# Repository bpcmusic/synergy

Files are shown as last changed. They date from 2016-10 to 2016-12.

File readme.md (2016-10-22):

#bpcmusic's dk synergy corner

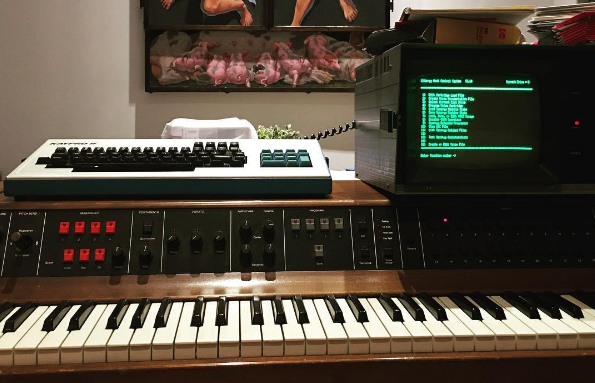
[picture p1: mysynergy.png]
My Synergy


I'm creating this archive as a place to document my attempts to restore a DK Synergy II+ (#1398) that was purchased in the fall of 2016 as a part of my #midlifesynthcrisis or #midilifecrisis. :) I'll also be sharing a lot of photos on [my personal Instagram](http://instagram.com/bpcmusic).

Along the way, I'll store the relevant things that I learn here. While I am relatively handy with electronics, this is the first vintage synth project that I've undertaken. 

##My Journey

* [Taking the Synergy Apart](teardown.md)
* [Replacing the Aging Capacitors](capacitors.md)
* Installing Headers for Board Connections
* [Restoring the Wood Case](case.md)
* [Replacing the Power Supply and Noisy Fan](powersupply.md)
* [Fixing Sticky Buttons](stickybuttons.md)
* [Connecting to the Kaypro II](kaypro.md)
* Replacing the Kaypro II Disk Drive with a Floppy Emulator
* [Building a Cartridge PCB and 3D Printed Shell](cartridge.md)
* [Keyboard Refurbishment](keyboard.md)

##Handy Resources

* [Synergy Resource Page](http://users.ece.gatech.edu/lanterma/synergy/)
* [Facebook Synergy Group](https://www.facebook.com/groups/synergysynth/)
* [Yahoo Synergy Group](https://groups.yahoo.com/neo/groups/synergy-synth/info)
* [Vintage Synth](http://www.vintagesynth.com/misc/synergy.php)
* [Old Crow's Vintage Synth Tips](http://www.oldcrows.net/~oldcrow/synth/tips.txt)
* [HxC Floppy Emulator](http://hxc2001.free.fr/floppy_drive_emulator/)
* [Syntaur Synergy Parts](https://syntaur.com/synergy.html)

##Synergy Videos

* Rex Coggins has compiled a YouTube playlist that covers a whole bunch of Synergy-related videos up on YouTube; check it out at [https://www.youtube.com/playlist?list=PLffUjChiMD5i-BCu7Go9ABLnsAaPviy90](https://www.youtube.com/playlist?list=PLffUjChiMD5i-BCu7Go9ABLnsAaPviy90) 

##Nice Helpful Folks

* Major thanks to **Brian McLaren** (made a few of those YouTube videos up there). He has gone above and beyond with me helping get the instrument 100% with my software, EPROMs and general usage questions.
* Thanks to **Rex Coggins** for his advice and recommendations.
* Thanks to **Alexander Guelfenberg** at [Virtual Music](http://virtual-music.at/webseiten_e/zubehoer/dk.htm) - insanely nice and helpful in my trek to refurbish the Synergy.

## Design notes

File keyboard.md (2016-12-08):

[< BACK](readme.md)

#Keyboard Refurbishment

This section covers my refurbishment of the DK Synergy Keyboard. You will find details on removing the keys, cleaning/whitening, 3D printing actuator replacements, replacing the rubber bushings, and reinstalling the keys.

##On the Universal Keyboard Upgrade

There is a "universal keyboard upgrade" that you can find on the [Virtual Music site](http://virtual-music.at/webseiten_e/zubehoer/dk.htm). I reached out to Alexander Guelfenberg at Virtual Music about getting his upgrade and found it wasn't offered for the Synergy anymore. Here is what he shared with me:

	All items were fitting when I had my personal Synergy. And I saw that all PPG parts worked for that. 
	But then a client told me that his knobs are quite different so they did not fit.

I should point out that he is an insanely nice person and has been extremely helpful with my Synergy work.

##Removing Keys

Removing the keys from the Pratt-Read assembly is pretty straightforward. Screws in my Synergy Keyboard were easily managed using a 5/32" socket wrench. This was a little hard to find at my local Home Depot, it literally was the smallest socket that they had (and there was only one of them in stock).

I went ahead and labeled all of my keys with blue tape up on the metal bit. They are labeled themselves as to which location they fit, but in order to avoid having keys placed in different octaves than their original source, I took the OCD way out. I figured if the wear and yellowing was uneven across the keyboard, making sure that they keys were put back in their original octave would keep things looking as uniform as possible. Thus, I haven't documented the factory labeling scheme for the keys.

What I did learn quickly is that all white keys need to be removed from around any of the black keys for disassembly and the reverse for reassembly. Due to this (and due to the fact that my cleaning procedures are different for white vs. black keys), I removed all of the white keys first and then followed it up with the black keys.

My steps for removal of the keys:

1. Remove the screw at the fulcrum point (middle of the metal key bar).
2. Remove the metal side spring by gently lifting it off of the plastic actuator and releasing it to the side of the key.
3. Lift the key up by the back and, when released, slide the key forward. (The little metal spring that inserts into the back of the actuator will simply pop out.)
4. Carefully remove the rear screw that holds the actuator in place.
5. Slide the back dingus off of the actuator. Sorry - I don't know what else to call it. It is the plastic bit that sticks up and has a few holes on it. It connects to the actuator using a rubbery ring.

That's it.

    Note: I wasn't able to figure out how to separate the white plastic key from the metal bar safely. 
    I decided to leave it on and be very careful during the cleaning.

##Cleaning the Keys

I followed a procedure that I found here:

http://www.retrofixes.com/2013/10/how-to-clean-whiten-yellowed-plastics.html

*It is highly recommended to use eye protection and operate in a well-ventilated area.*

####White Keys

Check out the difference before and after cleaning:

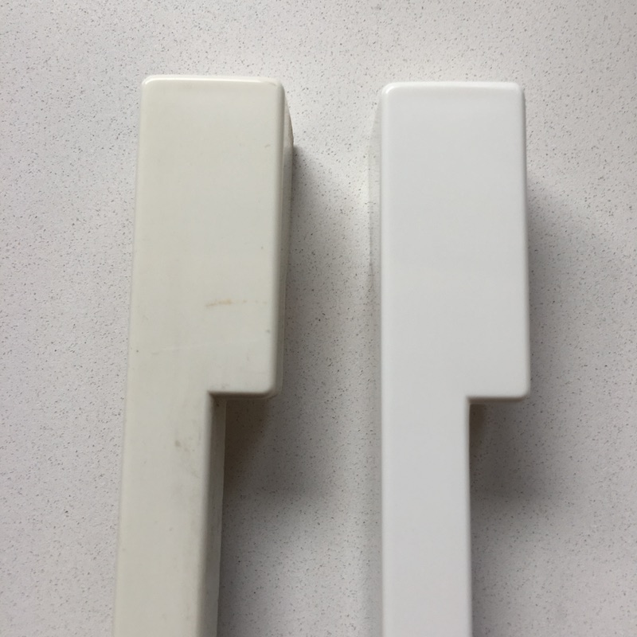
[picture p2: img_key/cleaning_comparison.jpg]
Old vs New


Left group hasn't been done; right group has:

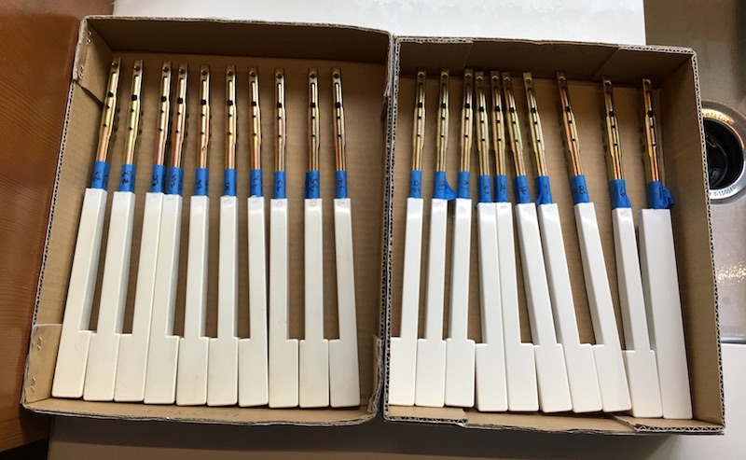
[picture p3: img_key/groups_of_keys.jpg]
Ready vs Done


**The Procedure:**

1. Wash the oil and filth off of the keys using an OxiClean + Water solution and a toothbrush. (Due to the fact that I could not remove the metal bits from the keys, I did not go through a soaking process.)
2. Liberally apply a hydrogen peroxide 12% solution (the Clairol Hair Color product below) to the plastic part of the key - careful to keep it off of the metal.
3. Place the keys under a strong UV light for 3-4 hours.
4. Immediately remove the keys, clean them with water, reapply the peroxide solution, and return them to the "UV bath" for another 3-4 hours.
5. Remove the keys, clean them with water and dry them.

Depending on the desired whiteness, I imagine that several more trips to the UV bath could be done. I elected to be conservative with my whiteness levels.

My homemade UV tank:

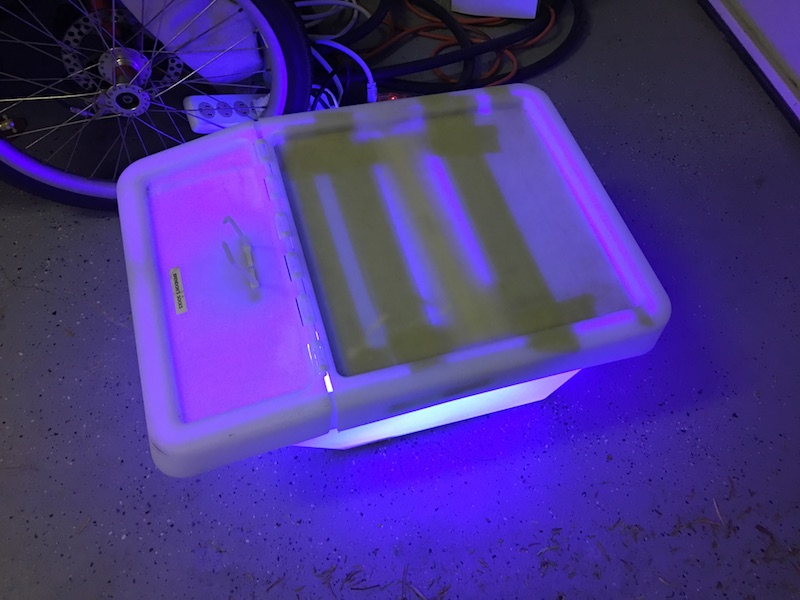
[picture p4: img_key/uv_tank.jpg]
UV Tank


I used two UV lamps I found on Amazon (and liberal amounts of duct tape):

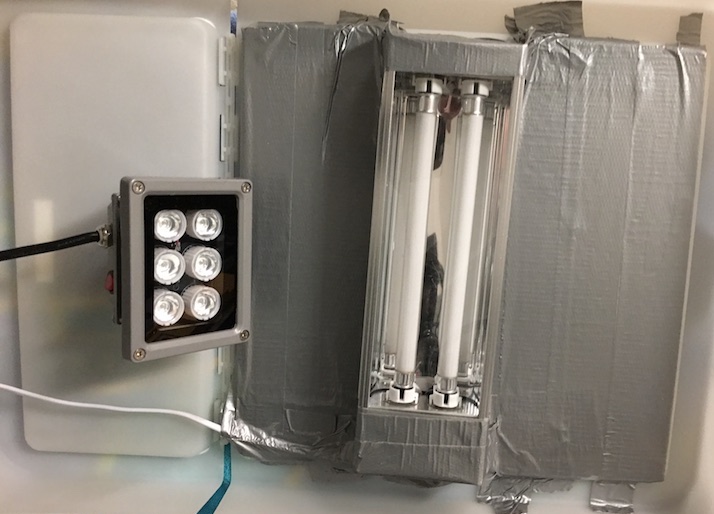
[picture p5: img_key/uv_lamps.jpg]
UV Lamps


    IMPORTANT: At no point do you want the peroxide to dry as it can scar the plastic surface of the keys. 
    Set an alarm or other timer. These things are irreplaceable as far as I can tell.

####Black Keys

I simply washed the keys using the OxiClean + Water Solution using a toothbrush. They cleaned up nicely.

##Key Actuators

I first cleaned the actuators with rubbing alcohol wipes as they were covered in a sticky substance. Yuk.

I found ten plastic actuators in my Synergy that were cracked or cracking. All of the damage was found at the joint where the screw enters the body of the actuator. The sticky substance was an aid in this as it helped find the cracked actuators by making the cracks stand out.

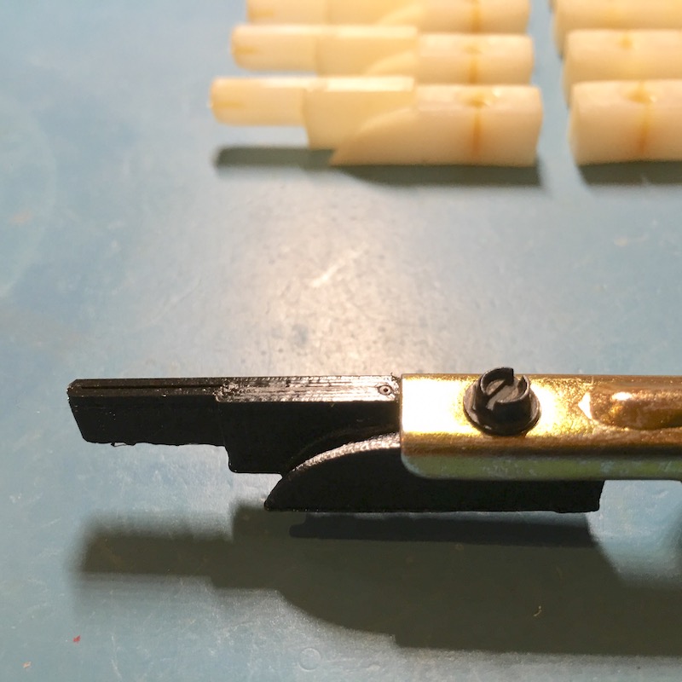
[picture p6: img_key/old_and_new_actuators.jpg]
New and Old Actuators


To solve this, I modeled and 3D printed replacements for the failing parts. I tried printing in both PLA and ABS and found that ABS was far superior in producing a part that worked mechanically. The PLA would start sticking after only a few keypresses; I have yet to replicate that behavior with the ABS printed parts. There are more abrasion-resistant 3D filaments - I have yet to test any of them.

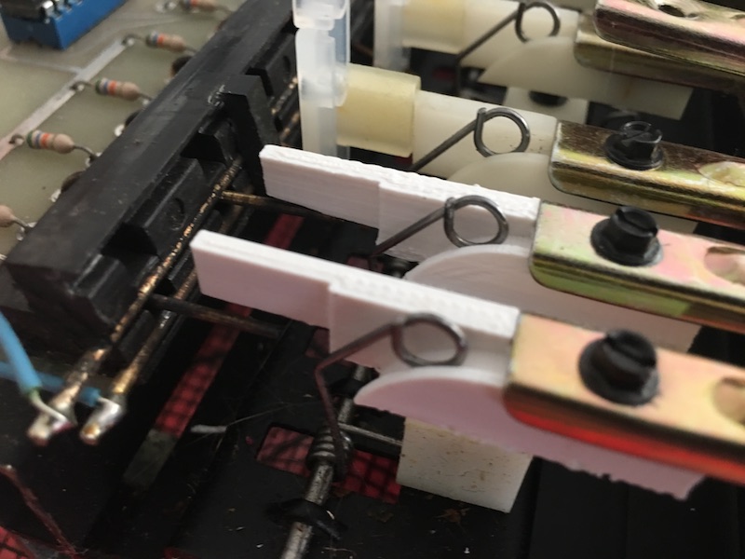
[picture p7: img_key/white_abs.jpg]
White ABS Actuators


Here are the files for the replacement actuator:

* [Download the OpenSCAD Model](actuator/actuator.scad)
* [Download the STL Part File](actuator/actuator.stl)

These files are released under the [cc-by-sa-3](https://creativecommons.org/licenses/by-sa/3.0/us/) license. Hopefully you find it helpful!

##Rubber Bushings

If you need new Rubber Key Bushings for the Pratt-Read keyboard assembly, Syntaur has them.

[Syntaur Link for Pratt-Read Rubber Bushings](http://syntaur.com/Items/4169.html)

The Synergy has 74 keys and, thus, needs 74 bushings for a total replacement. At the time of this writing, they were $0.70 USD per bushing.

I grabbed a full set. After inspecting my bushings, I realized that they were still doing pretty well. Rather than throwing them away, I went ahead and conditioned them with Armor All Original Protectant and reinstalled them. I'll keep the new ones for a rainy day.

*Using Armor All is the recommended treatment that I found for the rubber bits in the Keyboard.*

##Reassembly

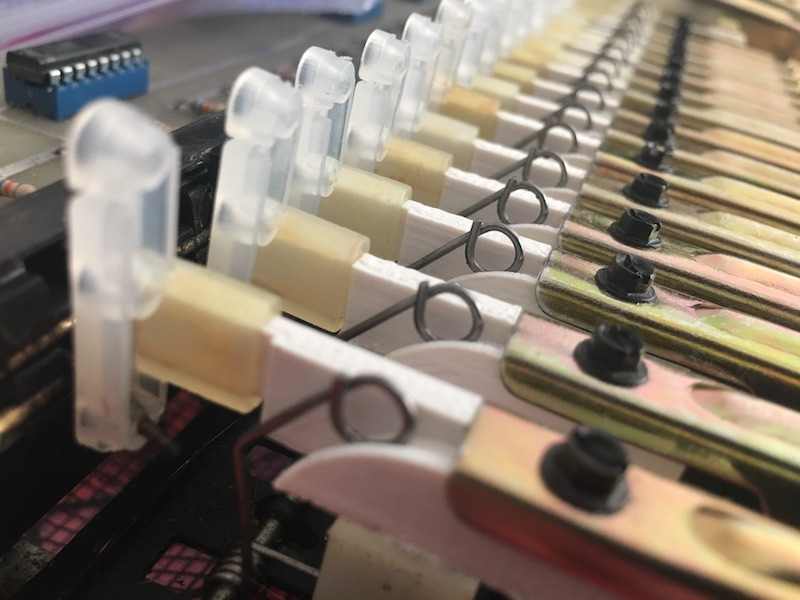
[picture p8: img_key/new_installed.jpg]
White ABS Actuators during Reassembly


Reassembly is simply the reverse of the removal process. Remember, do the BLACK KEYS first to make it easy on yourself.

1. Attach the actuator back to the far end of the metal key body. Careful not to over-tighten the screw.
2. Attach the dingus to the end of the actuator. I recommend treating the rubbery ring with a coating of Armor All prior to reattachment.
3. Slide the plastic end of the key under the lip at the front of the assembly.
4. Press the key down onto the white plastic fulcrum; you might need to make sure that the part that it attaches to is properly centered for easy reattachment.
5. Using some sort of clever implement (I used a pair of SMD tweezers), pull the metal spring up and back over the curved area of the actuator.
6. Reattach the screw at the fulcrum point. Again, careful not to over-tighten it.
7. Carefully manipulate the spring at the far end of the key back into the appropriate hole in the dingus. I was able to pull the spring back in a bit from the other side of the black metal bar so as to realign it with the hole.

##Products Used

* [OxiClean at Amazon](https://www.amazon.com/gp/product/B005GI8UOO/ref=oh_aui_search_detailpage?ie=UTF8&psc=1)
* [Clairol Professional Soy4plex Pure White Creme Hair Color Developer at Amazon](https://www.amazon.com/gp/product/B00A5ET16A/ref=oh_aui_search_detailpage?ie=UTF8&psc=1)
* General Cheap Toothbrushes (drugstore brand); I used a motorized one in addition to a few plain ones for extra fun.
* [6-LED UV Lamp for Curing LOCA UV GLUE - 110V at Amazon](https://www.amazon.com/gp/product/B0178KPN4W/ref=oh_aui_search_detailpage?ie=UTF8&psc=1)
* [HQMaster 110V 48W Curing UV Light Ultraviolet Lamp to Bake Loca Glue for Refurbish LCD no Handle at Amazon
](https://www.amazon.com/gp/product/B012ZNLZY4/ref=oh_aui_search_detailpage?ie=UTF8&psc=1)
* [Armor All 10228 Original Protectant at Amazon](https://www.amazon.com/Armor-All-10228-Original-Protectant/dp/B0007898UI)

##Research

I found these videos for Pratt-Read Keyboards - though the assemblies do not match the Synergy.

* [ARP Pro Pratt-Read Keyboard Restoration](https://www.youtube.com/watch?v=5iJtaW3bvK4)
* [Pratt-Read Key Removal on OB-Xa](https://www.youtube.com/watch?v=DmSz_JY4zZU)
* [Pratt-Read Keyboard Restoration Video](https://www.youtube.com/watch?v=VvMh64XNhEw)

##License for Original Materials

The original materials made available on this page are licensed under the [cc-by-sa-3](https://creativecommons.org/licenses/by-sa/3.0/us/) license.

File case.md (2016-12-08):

[< BACK](readme.md)

# Restoring the Wood Case

##Context and a Plan

So - my Synergy is currently a medium-brown wood. It has some damage, but isn't horrible. Basic scratches and light gouges around the body. Only one place on the primary face where a little of the surface is chipped off. Each of the four corners of the base is crushed in a bit.

My Synergy

My analysis is that this is what an upright piano looks like after a few moves in a family with toddlers. Rather than try to fix it myself, I'm looking for a piano refinisher in the LA area to fix it as I have no experience restoring wood with this type of damage.  I figure they would be the best with this kind of problem - especially since the body of the Synergy is like a big piece of wood furniture (like a piano).

Here is what it looked like when I purchased it:

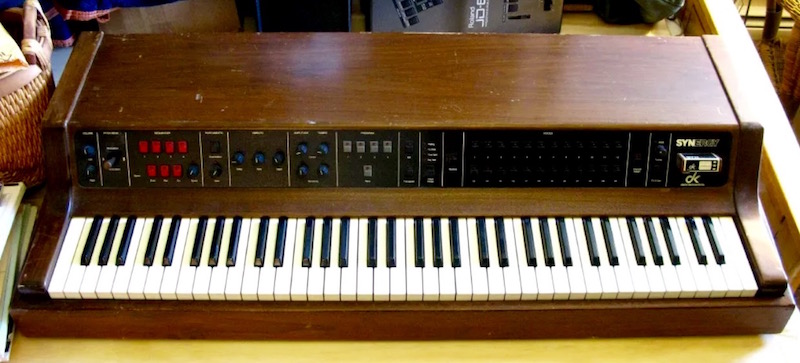
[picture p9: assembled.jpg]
Assembled


Note the damage to the corners of the base (all four are similar):

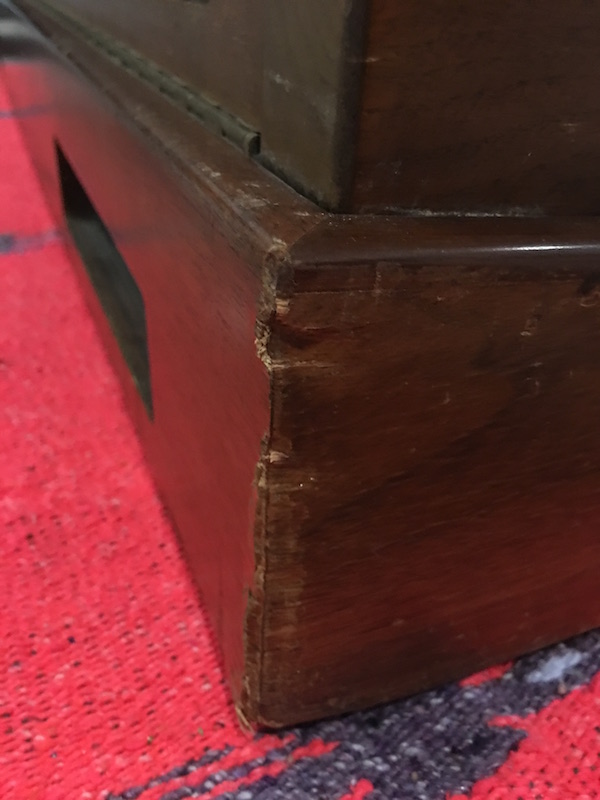
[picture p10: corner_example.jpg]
Corners


The fact that I've decided to bring in a professional refinisher opens up the question as to whether I'm going to keep the brown wood or do something else.

*Calm down, I'm not doing the Murf and the Magic Tones pink fur treatment. Though - you have to admit it would be awesome. :)*

I'm actually considering refinishing it in a black lacquer piano finish. Something like this:

Piano Black Synergy

Crossed with this:

LaCie Drive in Piano Finish

Should look beautiful. Couple of points:

* The ends of my brown Synergy are shaped a little differently and I'm not planning to change that. 
* The black Synergy keyboards that I've seen have a tolex-wrapped base. As I don't plan to travel with the instrument, if I piano-black the thing, I'll probably just do the whole body.

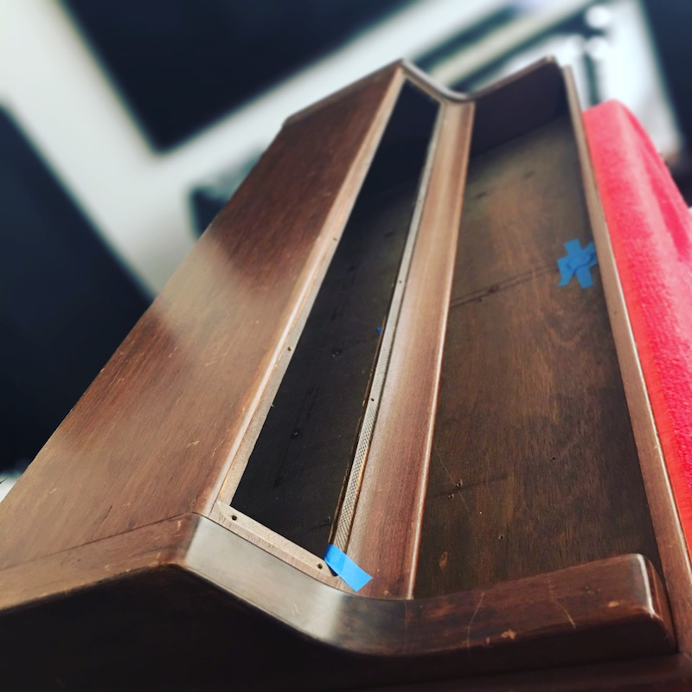
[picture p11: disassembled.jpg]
Disassembled


##Results

It turned out amazingly well. Total for the case refurbishment (repair and refinishing) was around $1300 in LA. Considering how banged up it was, they did a wonderful job.

Check out some early pictures:

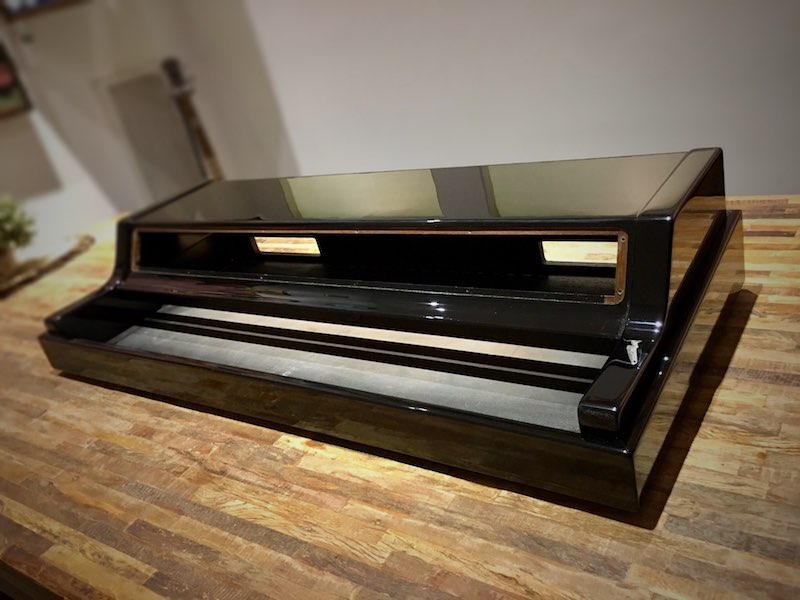
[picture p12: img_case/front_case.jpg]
Front Case


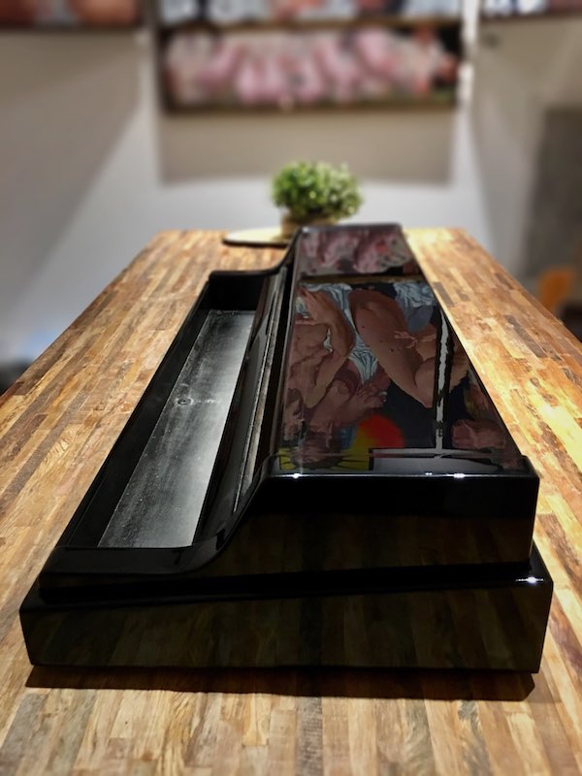
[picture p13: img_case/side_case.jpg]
Side Case


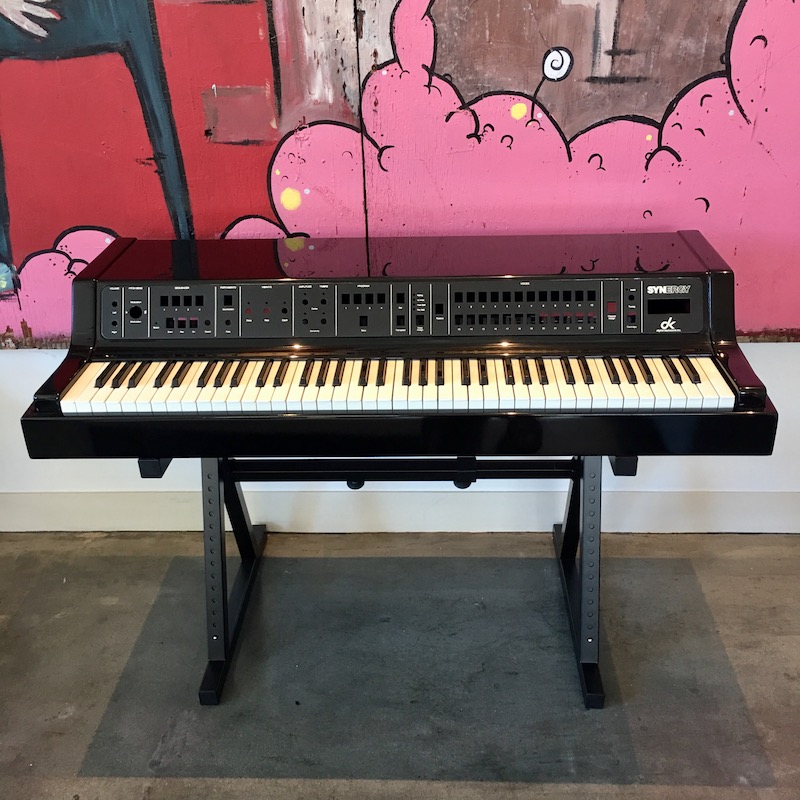
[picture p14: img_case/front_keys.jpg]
Front Keys


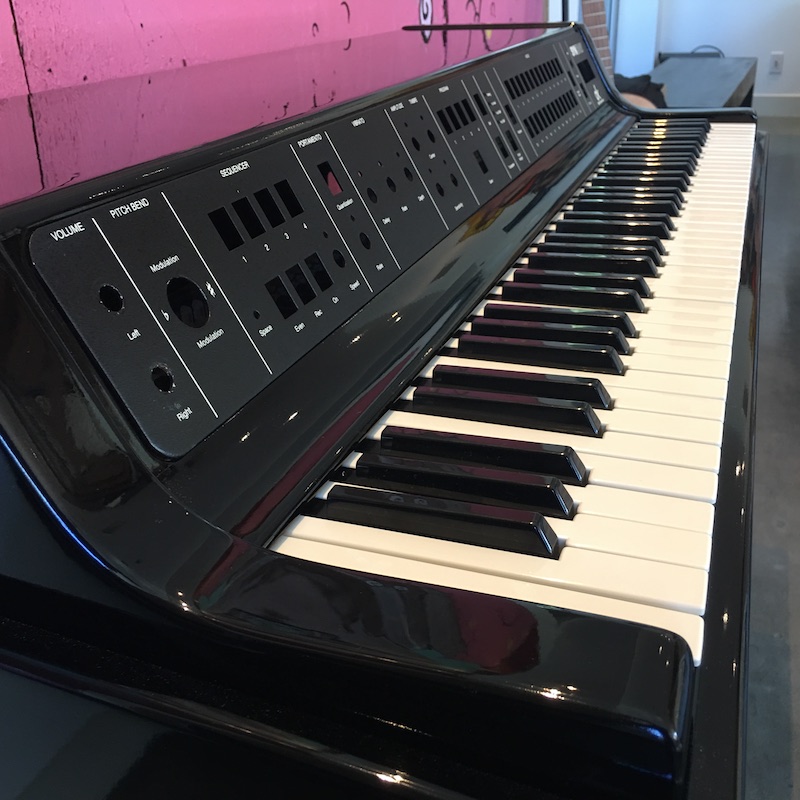
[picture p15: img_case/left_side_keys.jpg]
Left Side Keys


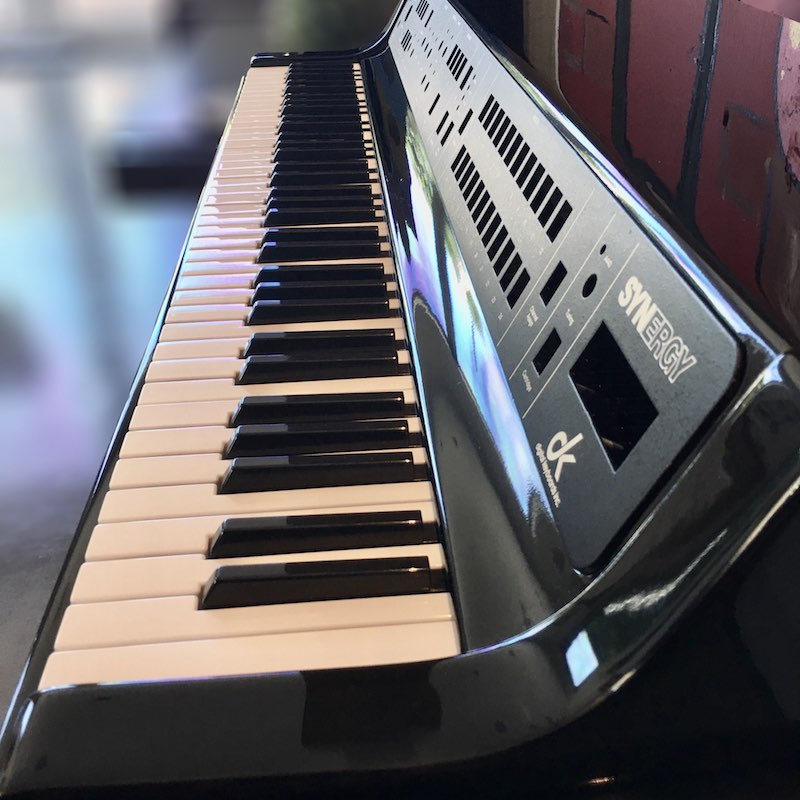
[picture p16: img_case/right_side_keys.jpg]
Right Side Keys


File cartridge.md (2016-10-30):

[< BACK](readme.md)

#Synergy Cartridge

I have a complete set of all of the EPROMs for the Synergy - including all of the cartridges. I'd like to fit these into actual cartridges to have along side my Synergy (as opposed to using some sort of socket adapter or a multi-cartridge device). 

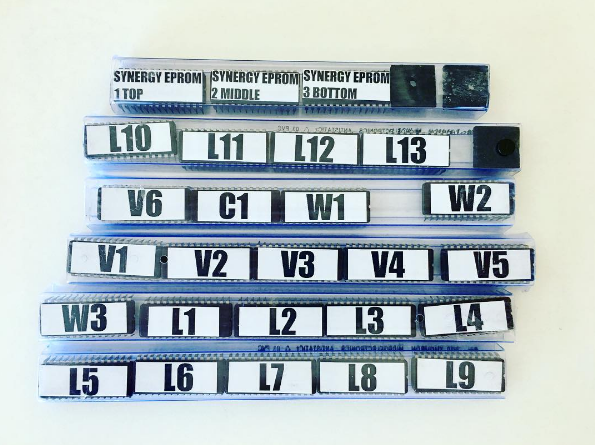
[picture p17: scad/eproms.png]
EPROMs


*I know what you are thinking. Yes, these are also available using SYNHCS on the Kaypro II (they are all archived on the collection of voice disks that I have), but I wanted to have a full set of cartridges to go with it so I don't have to always boot up the Kaypro II.*

According to Dan Wilson of Hideaway Studio, the Synergy uses cartridge bodies and PCBs that are compatible with the vintage Atari 400 computer game console. In my cursory research, this seems to be the case.  If I had just a few cartridges to do I could eBay a handful of cartridges, mod the PCB and be off to the races.

As I have 23 cartridges to make (and enjoy a good challenge), I decided to 3D print my own custom case (based off a vintage Synergy voice cartridge) and replicate the PCB in Eagle.

##MY PLAN:

* Design a new Cartridge Body in OpenSCAD [*DONE*]
* 3D Print 23 Cases [*In-Process*]
* Replicate the PCB in Eagle [*DONE*]
* Do a Test Run of the PCB at OSH Park [*In-Process*]
* Assemble, Test and Tweak the PCB
* Find and Affordable PCB Manufacturer that can Gold Plate the Edges
* Get >23 PCBs Made with Gold Plated Edges
* Assemble All Carts

##3D PRINTED CARTRIDGE BODY

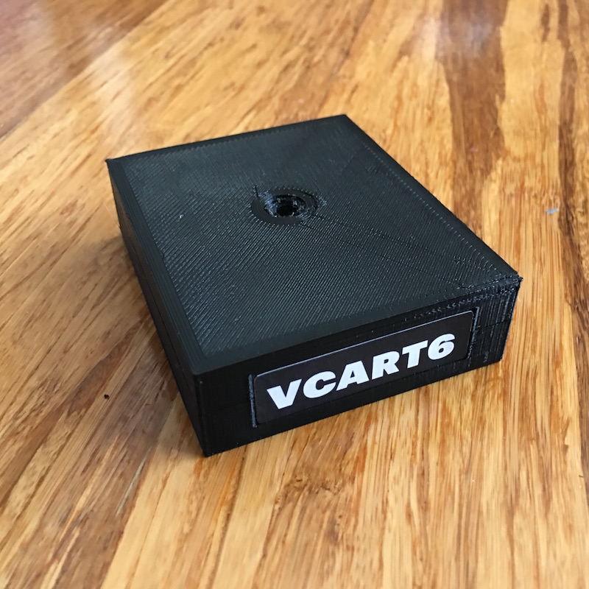
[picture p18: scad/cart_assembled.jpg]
Assembled Cartridge with Label


The cart body is in two parts - the top and the bottom. While it is close to the original, I've made some modifications to better support 3D printing. Primarily, there are now 5 little plastic studs in the four corners and top center to make the body way more rigid (the original only had one in the top center location). I also changed the label system to use a single 0.5" x 1.75" mailing label on the top end (as opposed to the wraparound label.

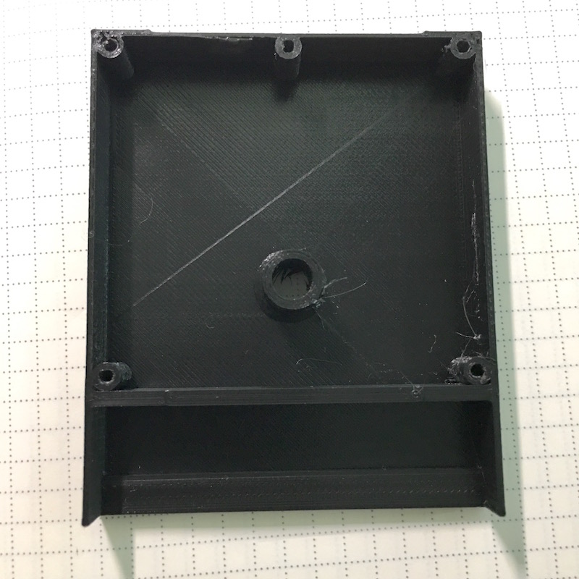
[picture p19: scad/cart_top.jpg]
Top

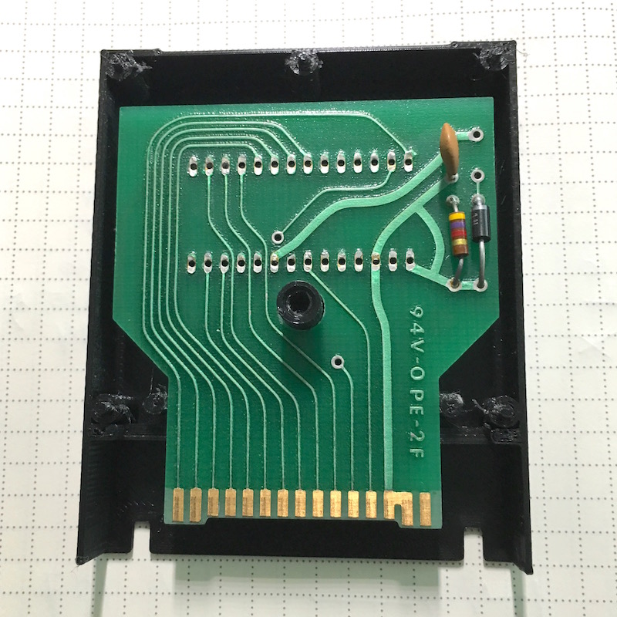
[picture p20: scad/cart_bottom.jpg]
Bottom


You are welcome to grab the STL and/or OpenSCAD files to play around with it (covered under the cc-by-sa-3 license; see the bottom of this page). I've been printing on my NewMatter Mod-T with PLA. If you are using a different printer, the tolerances may be different. Let me know if you have any issues.

* [Top STL File](scad/synergycart-top.stl)
* [Bottom STL File](scad/synergycart-bottom.stl)
* [OpenSCAD File](scad/synergycart.scad)

The cartridge is designed to support a standard 0.5" x 1.75" mailing label on the end; I ordered this product from Amazon to laser print my labels:

[Avery Easy Peel Return Address Labels for Laser Printers, 0.5 x 1.75 Inches, White, Pack of 2000 (5267)](https://www.amazon.com/gp/product/B00004Z5QP)

You will also need a 1/2 inch #6 wood screw (0.138" major thread diameter and .279" head diameter) with a crown top for each cartridge.

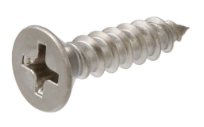
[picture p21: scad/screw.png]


##CARTRIDGE PCB

As opposed to using the Atari 400 cartridge PCB (there is a schematic in the Additional Resources if you are curious), I decided to take apart a Synergy Cartridge and reverse engineer it with a voltmeter and high-precision calipers. I then replicated it in Eagle. Why? Cuz it was fun. ;)

Here are the rendered test PCBs from OSH Park:

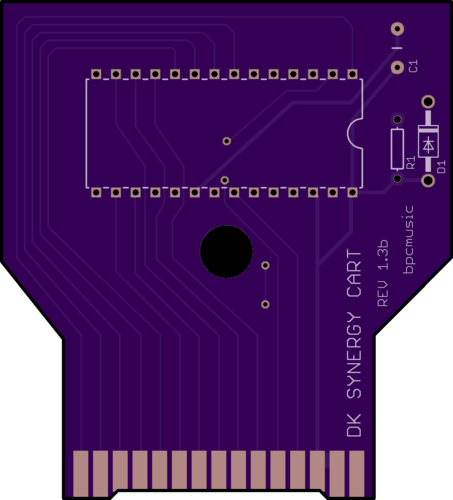
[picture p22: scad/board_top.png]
Top of Board

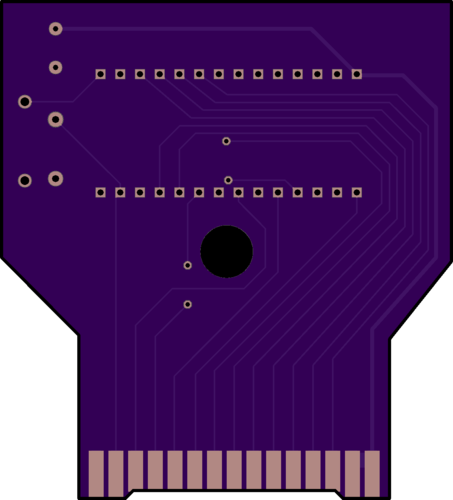
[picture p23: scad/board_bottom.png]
Top of Board


####EEPROM Pin Mapping

Here are some notes I made during the process:

| Top Edge | EEPROM Pin |  | Bottom Edge | EEPROM Pin |
| --- | --- | --- | --- | --- |
| T1 | 1 | | B1 | X |
| T2 | 7 | | B2 | 27 |
| T3 | 8 | | B3 | 21 |
| T4 | 9 | | B4 | 23 |
| T5 | 10 | | B5 | 19 |
| T6 | 16 | | B6 | 15 |
| T7 | 17 | | B7 | 2 |
| T8 | 13 | | B8 | 24 |
| T9 | 12 | | B9 | 25 |
| T10 | 11 | | B10 | 3 |
| T11 | 18 | | B11 | 4 |
| T12 | 22 | | B12 | 5 |
| T13 | 26/28 | | B13 | 6 |
| T14 | 26/28 | | B14 | 14/20 |
| T15 | X | | B15 | 14/20 |

There is also a through-hole resistor (4k7), capacitor (.1uf) and diode on the original cartridge. You can find my reverse-engineered schematic below that shows where to place these:

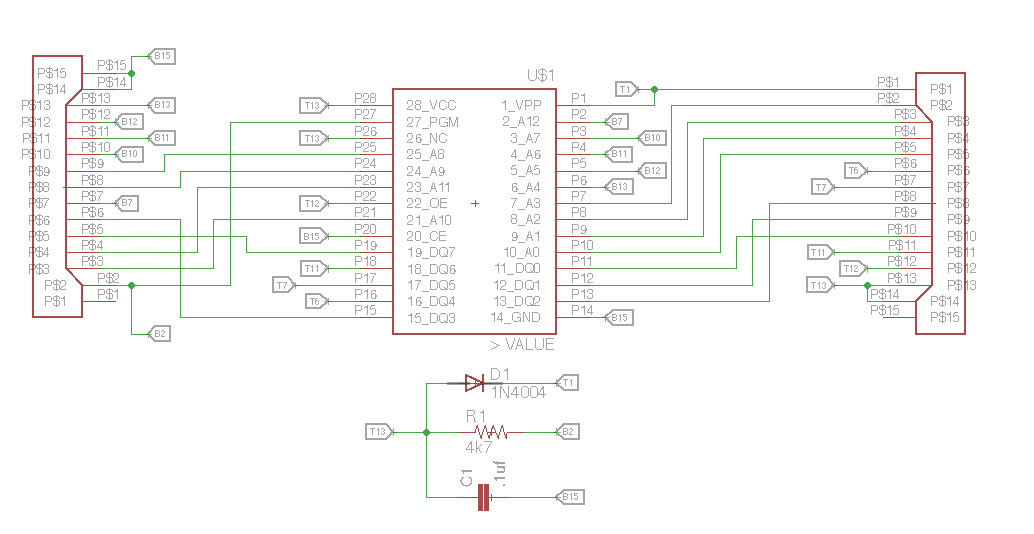
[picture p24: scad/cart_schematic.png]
Schematic


I'll post the Eagle Files, Gerbers and BOM once it is tested and working. (They will also be covered by the cc-by-sa-3 license; see the bottom of the page.)

Finally, there is a link to the EEPROM data sheet in the Additional Resources section below.

##ADDITIONAL RESOURCES

* [AM2764DC EEPROM Datasheet](scad/AM2764DC.pdf)
* [PDF for Atari 400 PCB](http://www.grandideastudio.com/wp-content/uploads/pp_atari8bit_instructions.pdf) from Grand Idea Studio (not used)
* [Page with Link to Gerbers File](http://www.grandideastudio.com/portfolio/pixels-past/) from Grand Idea Studio (not used)
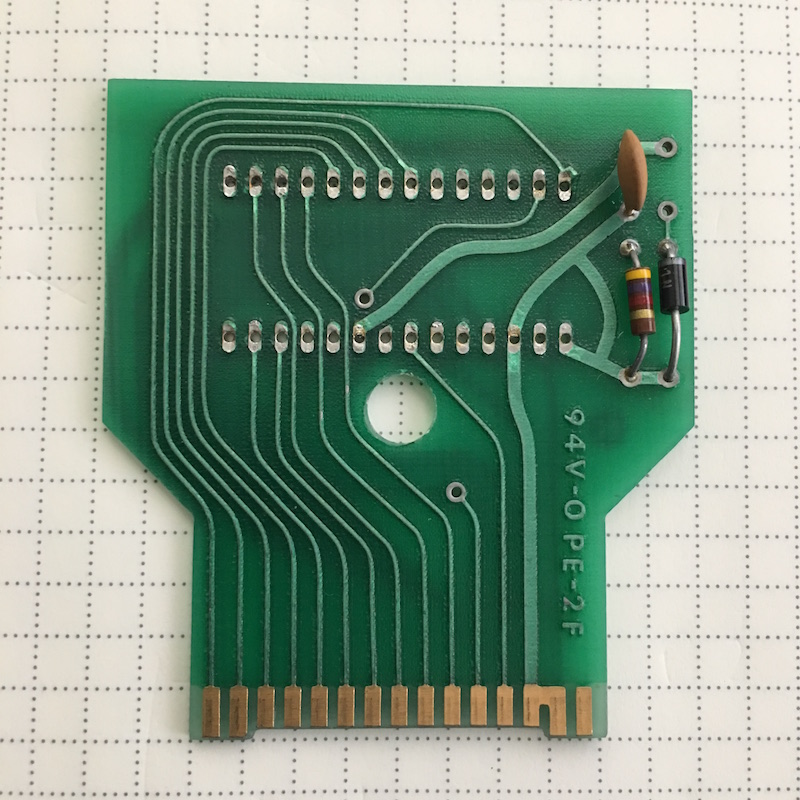
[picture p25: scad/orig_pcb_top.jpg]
Original PCB Top
* Original PCB Top: 
* Original PCB Bottom: Original PCB Bottom

##License for Original Materials

The original materials made available on this page are licensed under the [cc-by-sa-3](https://creativecommons.org/licenses/by-sa/3.0/us/) license.

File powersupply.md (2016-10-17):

[< BACK](readme.md)

#Power Supply Upgrade

The following power supply was recommended to me for the Synergy (it has been tested and used with several refurbishments):

**Hengfu HF-100W-SF5**

Hengfu HF-100W-SF5

* Output: 5V/20A
* RIP/Noise: 100mv
* Eff: 78%

[High-Level Data Sheet](https://www.mpja.com/catalog/Hengfu%20Power%20Supplies.pdf)

[Purchase Link from MPJA](http://www.mpja.com/5-Volt-Power-Supply-20A-100W-Switching-Hengfu/productinfo/16011+PS/)

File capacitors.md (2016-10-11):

[< BACK](readme.md)

#Synergy Capacitor Replacement

This page will run down the list of Tantalum Capacitors that I replaced in my Synergy, board by board.

D/A Board

Part # | Marking | Value | Mouser PN 
--- | --- | --- | ---
C1 |  |  |
C2 |  |  | 
C3 |  |  |
C20 |  |  |
C21 |  |  |
C22 | 1-35 2 |  |
C23 |  |  |
C24 | 1-35 2 |  |
C25 | 10-25 2 |  |

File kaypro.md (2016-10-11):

[< BACK](readme.md)

#Connecting to the Kaypro II

Getting the Synergy II+ working with the Kaypro isn't hard, but it can be tricky if you don't know all the steps. Here is what I had to do to get it running.

####Serial Connection Cable

Having the proper serial cable is critical for communication. This is the pinout for the DB-25 connector that is required to go between the two devices

Left Signal Name | L DB-25 | R DB-25 | R SN
---|---|---|---
FG (Frame Ground) | 1 | 1 | FG
TD (Transmit Data) | 2 | 3 | RD
RD (Receive Data) | 3 | 2 | TD
RTS (Request to Send) | 4 | 5 | CTS
CTS (Clear to Send) | 5 | 4 | RTS
SG (Signal Ground) | 7 | 7 | SG
DSR (Data Set Ready) | 6 | 20 | DTR
DTR (Data Terminal Ready) | 20 | 6 | DSR

####Setting Baud Rate

Connecting is one thing, but you need to make sure that your Kaypro II is running the proper baud rate to the Synergy. The way to do this is to execute the BAUDM program on the Synergy Utilities disk and set it to 9600 (option G). You will need to do this EVERY TIME you want to connect the computer and your Synergy.

####Testing the Connection

Ok - ready to test? Here you go:

1. Connect the cable
2. Boot the Kaypro
3. Set the Baud Rate
4. Launch SYNHCS (I used the last version from 85)
5. Start your Synergy
6. Press "RESTORE" then "PROGRAM-4" on the Synergy to put it into connection test mode
7. Execute option 13 on SYNHCS "Test Synergy Link"
8. Press the Any Key ;)
9. Look for Happy Tests

####Is It Not Happy?

If it isn't, you may need to set jumpers inside the Synergy to get the baud rate set properly at that end. I didn't have to do this, but the Synergy II Manual Addendum suggests that the following jumpers set the rate (found at the font left corner of the processor board, which is the far right large board).

switch | rate
---|---
 ee | 1200 baud
 dd | 2400 baud 
cc | 4800 baud
bb | 9600  baud
aa | 19200 baud

Jumpers listed as found and oriented on the serial interface card (top to bottom). Mine was set to "bb" - 9600 baud.

####Kaypro CP/M Notes

The whole Kaypro thing can be a little confusing due to all of the variants of the operating systems and hardware models. Throw into the mix that the hardware is ancient and the drives are seriously aging. My Kaypro II works pretty well - but only with the F variant of the operating system (G just hangs the thing). I've also have some bum outer tracks on my A drive - but I've been able to successfully make copies of most of the Synergy related disks and I can successfully execute SYNHCS - they synergy editor and voice management software.

I used COPY to copy most disks; for those that failed to copy successfully, I used the following procedure:

**Copying Disks that Won't Copy with COPY:**

I had the best luck following the steps below for each disk that I wanted to copy that was failing the COPY command; it seemed more successful to format and immediately use PIP top copy as opposed to formatting all disks and then performing all of the PIP copies. Could have been superstition, but I had much better progress when I started reformatting just before my filecopy. I also wore one red shoe during the process. ;)

* Put your OS in drive A and a blank disk in drive B
* Format the disk in b using INITDISK; select option 0 for KAYPRO and press RETURN to format the disk
* Press return to exit INITDISK when the format is complete
* Type PIP in the console to get the PIP command prompt
* Replace your OS disk with the disk you want to copy
* Type "B:=A:*.*"
* When complete, replace your OS disk in drive A and hit CTRL-C to do a soft boot

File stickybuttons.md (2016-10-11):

[< BACK](readme.md)

#Sticky Buttons

There are seven switches on my Synergy that are sticking and requiring that they be pulled upwards to unlatch.

* Sequencer - Even Switch (1 Red)
* Transpose Switch (1 Black)
* Voices: 1, 2, 10, 16, 17 (5 Black)

The voices buttons are tricky as they prohibit their vertical pair from being recognized when stuck in a down state.

Need to repair 6 Black and 1 Red switches.

--

New part option from Syntaur:

* [Black Switch](https://syntaur.com/Items/4875.html)
* [Gray Switch](https://syntaur.com/Items/4876.html)

Syntar also has a few other options for Synergy parts at: [https://syntaur.com/synergy.html](https://syntaur.com/synergy.html).

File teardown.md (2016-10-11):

[< BACK](readme.md)

#Taking Apart the Synergy

Followed the instructions in the "DK-1 Operating System V 2.42 - Installation" document for the diassembly; presenting a shortened version here with a little more detail on the things that I did during the process.

Synergy Screws

####1. OPENING THE CASE

1. Balance the Synergy on its Back Panel - always hold carefully with one hand. It doesn't feel like it wants to stand there on its own.
2. Using a #3 screwdriver - remove the 4 screws marked "A"
3. Place the Synergy bottom-down and slightly overhang the keyboard over the edge of your workspace
4. Come under the Synergy and using a #3 screwdriver, remove the two screws marked "B"
5. Using a #2 screwdriver, remove the two screws marked "C"
6. *Do not do anything crazy after this point like tilting the Synergy - the keyboard is completely unsecured (except for a fragile little ribbon connector)*
7. Gently lift the top of the Synergy (above the Keyboard) using the two end blocks on either side of the keyboard.

####2. REMOVING THE KEYBOARD

Keyboard

1. Remove the ribbon connector from the upper right of the keyboard; do it carefully and "DO NOT PULL ON THE WIRE" (quoting the aforementioned document). It suggests using a flathead screwdriver - I used needlenose pliers.
2. Get a helper to hold the top of your Synergy - in the next step you remove the keyboard assembly, which causes a lot of weight to leave the base of the keyboard. Mine wanted to tip over - hence the helper.
3. Put a few things adjacent to the boards in the base of your Synergy to balance the weight with the top. I used 10 lbs of padded hand weights way at the front - which was just about enough.

####3. REMOVING THE BOARDS

Time to remove the three main boards from the inside of the Synergy. Before you start, load up on some anti-static bags. [12x16 Anti-Static Bags at Amazon](https://www.amazon.com/gp/product/B016WRZ3JW).

Here are the boards.

Left | Center | Right
--- | --- | ---
D/A Board | Voice Board | Processor Board + RS232 and Programming Daughterboards

DAC Board:

DAC Board

Voice Board:

Voice Board

Processor Board:

Processor Board

1. Mark and Label Everything - there are a lot of wires *everywhere*.
2. Take a lot of photos. 
3. Take a few more photos. ;)
4. Get some big anti-static bags to store your boards; the largest ones I was able to find we 12x16 and didn't quite fit the two larger boards. By cutting down one side I was able to use two bags to contain each board.
5. Disconnect all of your labeled wiring from the three boards. Again - do not pull on the ribbons, use pliers and a flathead screwdriver to carefully remove them.
6. Remove the rubber bumpers that hold the boards in place one board at a time - carefully placing the boards into antistatic bags along the way. I went left to right.

####4. DISCONNECTING THE DAUGHTERBOARDS

Was able to carefully remove the smaller of the two (the RS232 board); the EEPROM board is pretty snug for me. Going to put that on hold until I get to the header installation.

####5. REMOVING THE MIDI ASSEMBLY & AUDIO PANEL

Audio Panel

1. Remove the six screws from the MIDI panel and store the whole assembly away.
2. Remove the six screws from the Audio panel and store the whole thing (wires and all) carefully away.

####6. REMOVING THE POWER SUPPLY

The power supply is held into the body of the Synergy by the screws on the back of the chassis - for of these screws hold the Synergy nameplate in place. I removed them while the case was open so that gravity kept the power supply box in place. To be safe, I also put a bunch of foam in the now empty Synergy body to catch the thing if it slides down while being removed.

####7. BEHIND THE FRONT PANEL

Top Without Daughterboard

1. Remove all of the knobs from their shafts on the front panel.
2. Remove all of the screws around the back of the panel that come through the wood body. Then wonder why you can't pop the whole thing out. But, don't try. Bad things will happen.
3. Remove the hanging daughterboard by removing the spacer screws (there are 13). Remove all but the outside ones first, then remove the end ones while carefully supporting the board. The headers in the middle will disconnect easily.
4. Wrap up that daughterboard in an anti-static bag.
5. Take some photos of the spacer pattern - don't want to forget it.
6. Remove the right circuit board by removing spacers and then the remaining screws. Careful to cradle it when you are down to the last two outside ones. Then, get that thing in an anti-static bag. I had to cut one in half to cover both sides of the thing.
7. Remove the left circuit board by removing the spacers and then the remaining screws. Cradle it when you are down to the last two outside ones - and don't forget to carefully disconnect the wire that is coming from the area of the joystick and potentiometers.
8. Remove the two nuts that hold the joystick in place, then remove the ground wire and then the final nut. Remove the joystick. Mark the top and store it away.
9. Remove the two potentiometers by unscrewing the nuts that are on the front of the potentiometers.

####8. PANEL & MISC

1. Carefully pop out the panel. Might have to softly tap on some of the screws that go through the wood body to loosen it up. Mine wanted to catch a bit on the wood around it and cause more problems - but I thankfully kept it under control.
2. Finish up by removing the vent grill (noting its orientation).
3. Check that the washers that sat under the keyboard assembly aren't loose - four of mine were.

---

Here is what it looked like when I was all done:

Disassembled

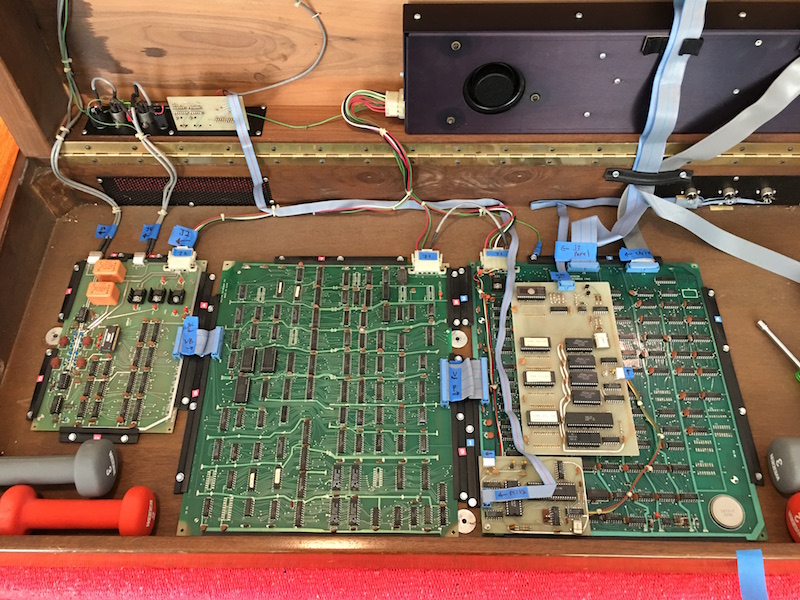
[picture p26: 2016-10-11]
boards.jpg

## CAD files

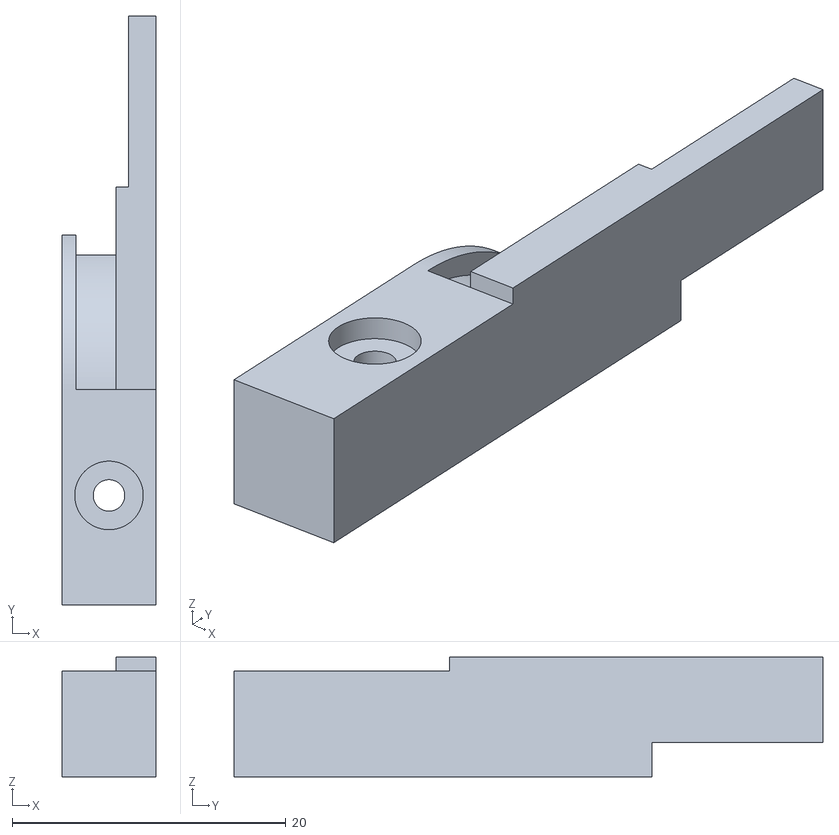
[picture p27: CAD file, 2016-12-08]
actuator/actuator.stl
6.85 x 43.0 x 8.75

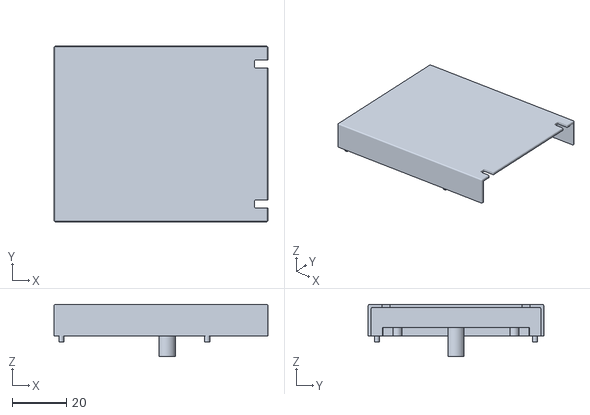
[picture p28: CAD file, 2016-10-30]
scad/synergycart-top.stl
78.5 x 64.4 x 19.2

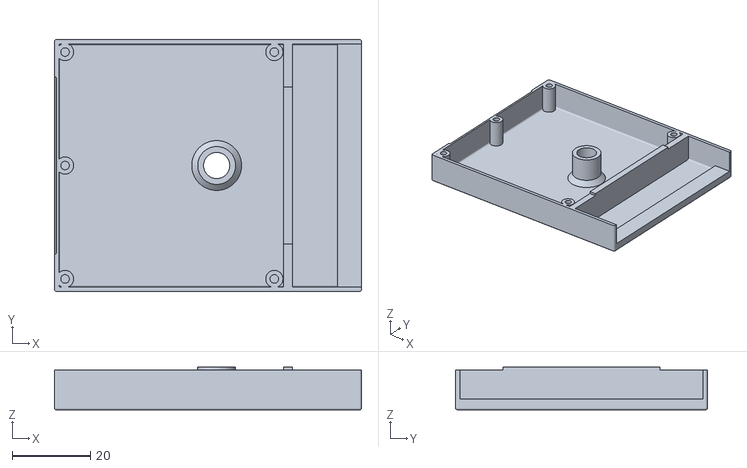
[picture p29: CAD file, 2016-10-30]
scad/synergycart-bottom.stl
78.5 x 64.4 x 10.9

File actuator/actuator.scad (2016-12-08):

$fn=200;

// full size of object (bounds)
fullDepth           = 43;
fullHeight          = 8.75;
fullWidth           = 6.85;

// screw area
screwHeight         = 7.75;
screwDepth          = 15.75;

// screw hole
screwInsetDiameter  = 5;
screwInset          = 1.3;
screwHoleDiameter   = 2.3;
screwCenterY        = 5.5 + (screwInsetDiameter / 2);
screwCenterX        = fullWidth / 2;

// upper arm
armWidth            = 2.9;
armDepth            = 14.75;

// forearm
forearmWidth        = 2;
forearmDepth        = fullDepth - screwDepth - armDepth;
forearmHeight       = 6.25;

// swoop ridge
swoopRidgeWidth     = 1;
swoopRidgeDepth     = 27 - screwDepth;

// swoop
swoopWidth          = fullWidth - armWidth - swoopRidgeWidth;
swoopMaxHeight      = 6.5;
swoopInset          = 1;
swoopRadius         = 12.040322580645157;

// OBJECT

// screw area and holes
difference(){
    cube([fullWidth,screwDepth,screwHeight]);
    union(){
        translate([screwCenterX,screwCenterY, -.5])
            cylinder(fullHeight+1, d=screwHoleDiameter, d=screwHoleDiameter);
        translate([screwCenterX,screwCenterY, screwHeight-screwInset])
            cylinder(screwInset+.5, d=screwInsetDiameter, d=screwInsetDiameter);
    }
}

// upper arm
translate([fullWidth - armWidth, screwDepth, 0])
    cube([armWidth, armDepth, fullHeight]);

// forearm
translate([fullWidth - forearmWidth, screwDepth + armDepth, fullHeight-forearmHeight])
    cube([forearmWidth, forearmDepth, forearmHeight]);



difference(){
    union(){
        translate([0, screwDepth, screwHeight - swoopRadius]){
            rotate([90,90,90])
                cylinder(swoopRidgeWidth, swoopRadius, swoopRadius);
        }
        translate([0, screwDepth - swoopInset, screwHeight - swoopRadius - swoopInset]){
            rotate([90,90,90])
                cylinder(fullWidth, swoopRadius, swoopRadius);
        }
    }    
    union(){
        cube([fullWidth,screwDepth,screwHeight]);
        translate([0,0,-fullDepth]) {
            cube([fullDepth,fullDepth,fullDepth]);
        }
    }
}   

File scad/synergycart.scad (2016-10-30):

$fn = 50;

DRAWTOP = true;
DRAWBOTTOM = false;

// half
half = 10.2;

// rounding of edges
rounded = 1;

// body
w = 78.55;
h = 64.45;
d = 21.75;
thickness = 2.2;

// bottom lip
lip = 6.13;

// bottom wall
wallfromend = 20;
wallwidth = 2.3;

// pcbhole
pcbinset = 5.3;
pcbfromtop = 8.5;

// bottom pcb support
supportfromend = 12.2;
supportheight = .75;

// centerhole
bottomcenterholeouterradius = 4.85;
bottomcenterholeinnerradius = 3.35;
bottomcenterpostscrewhole = 1.76;
bottomcenterpostscrewdepth = 13;
centerholefromtop = 41.5;

// body label inset (not used)
hlabelinset = 3.5;
wlabelinset = 15.5;

// avery end size
davery = 12.7;
havery = 44.45;
averypadding = 1;

// board bounders
bounderinset = 10.75;
bounderfromtop = 55.5;
bounderradius = 1.6;

// friendly board support
friendlyboardsupportfromtop = 28.5;

// chomps
chompinset = 5;
chomplength = 5;
chompwidth = 3;

// ALL SIDES
difference(){
    union(){
        difference() {
            shell();
            union(){
                if(!DRAWTOP)
                {
                translate([0, 0, half])
                    cube([w + thickness + rounded,h + thickness + rounded,d]);
                }
                if(!DRAWBOTTOM)
                {
                    cube([w + thickness + rounded,h + thickness + rounded,half]);
                }
            }
        }
        bottomelements();
    }
    bodyholes();
}
topelements();

module topelements(){
    // TOP ONLY
    if (DRAWTOP){
        
        // dinguses
        // center dingus
        translate([thickness + (rounded / 2),h/2,half - thickness])
            cylinder(d - half + thickness, thickness / 2.33, thickness / 2.33);
        // top right
        translate([thickness + (rounded / 2),thickness + rounded,half - thickness])
            cylinder(d - half + thickness, thickness / 2.33, thickness / 2.33);
        // top left
        translate([thickness + (rounded / 2),h - thickness - rounded,half - thickness])
            cylinder(d - half + thickness, thickness / 2.33, thickness / 2.33);
        // wall left
        translate([w - wallfromend - wallwidth,thickness + rounded,half - thickness])
            cylinder(d - half + thickness, thickness / 2.33, thickness / 2.33);
        // wall rigth
        translate([w - wallfromend - wallwidth,h - thickness - rounded,half - thickness])
            cylinder(d - half + thickness, thickness / 2.33, thickness / 2.33);
        
        // middle screw thing
        translate([centerholefromtop, h/2, thickness/4])
            difference(){
                cylinder(d - thickness/4, bottomcenterholeinnerradius * .9, bottomcenterholeinnerradius * .9);
                union(){
                    // main hole
                    cylinder(bottomcenterpostscrewdepth, bottomcenterpostscrewhole, bottomcenterpostscrewhole);
                    // triangle for screw top
                    cylinder(1.5 * thickness, bottomcenterholeouterradius, bottomcenterpostscrewhole);
                }
            }
        

        
    }
}

module bottomelements() {
    // BOTTOM ONLY
    if (DRAWBOTTOM){
        // bottom pcb support
        translate([w - wallfromend, supportfromend, half])
            cube([wallwidth, h - (2 * supportfromend), supportheight]);

        // bottom dinguses
        // top center
        translate([thickness + (rounded / 2),h/2,0])
            difference(){
                cylinder(half, thickness, thickness);
                translate([0, 0, thickness])
                    cylinder(half + thickness, thickness / 2, thickness / 2);
            }
        // top left 
        translate([thickness + (rounded / 2),thickness + rounded,0])
            difference(){
                cylinder(half, thickness, thickness);
                translate([0, 0, thickness])
                    cylinder(half + thickness, thickness / 2, thickness / 2);
            }
        // top right
        translate([thickness + (rounded / 2),h - thickness - rounded,0])
            difference(){
                cylinder(half, thickness, thickness);
                translate([0, 0, thickness])
                    cylinder(half + thickness, thickness / 2, thickness / 2);
            }
        // wall left 
        translate([w - wallfromend - wallwidth,thickness + rounded,0])
            difference(){
                cylinder(half, thickness, thickness);
                translate([0, 0, thickness])
                    cylinder(half + thickness, thickness / 2, thickness / 2);
            }
        // wall right
        translate([w - wallfromend - wallwidth,h - thickness - rounded,0])
            difference(){
                cylinder(half, thickness, thickness);
                translate([0, 0, thickness])
                    cylinder(half + thickness, thickness / 2, thickness / 2);
            }
            
        // bottom screw hole
        translate([centerholefromtop, h/2, 0])
            difference(){
                union(){
                    cylinder(half + supportheight, bottomcenterholeouterradius, bottomcenterholeouterradius);
                    cylinder(4 * supportheight, bottomcenterholeouterradius * 1.5, bottomcenterholeouterradius);
                }
                translate([0, 0, -thickness/2])
                    cylinder(half + supportheight + thickness, bottomcenterholeinnerradius, bottomcenterholeinnerradius);
            }
    }    
}

module bodyholes() {
    // hole for screw
    translate([centerholefromtop, h/2, 0])
        cylinder(half + supportheight + thickness, bottomcenterholeinnerradius, bottomcenterholeinnerradius);
    
    // inset for screw
    translate([centerholefromtop,h/2,-rounded/2])
        cylinder(thickness/2, bottomcenterholeouterradius, bottomcenterholeouterradius);

    // avery label (1.75" x .5")
    translate([-rounded/2, (h - havery - averypadding) / 2 , (d - davery - averypadding) / 2])
        rounded_cube([rounded, havery + averypadding, davery + averypadding], rounded);
    
    // top chomps
    translate([w - chomplength, chompinset, d - thickness])
        rounded_cube([chomplength * 2, chompwidth, 2 * thickness], 1);
    translate([w - chomplength, h - chompinset - chompwidth, d - thickness])
        rounded_cube([chomplength * 2, chompwidth, 2 * thickness], 1);
    
}

module shell(){
    // emptied out body
    difference(){
        difference(){
            rounded_cube([w,h,d], rounded);
            translate([thickness / 2, thickness / 2, thickness / 2])
                rounded_cube([w,h - thickness,d - thickness], 1);
        }
    }

    // support lip at insert point
    translate([w - lip, thickness / 4, thickness / 4])
        cube([lip, h - (thickness / 2), thickness ]);

    difference(){
        // wall for pcb support
        translate([w - wallfromend, thickness / 2, 0])
            cube([wallwidth, h - (thickness/1), d]);

        // pcb hole
        translate([w - wallfromend - (thickness / 2), pcbinset, half])
            cube([wallwidth + thickness, h - (2 * pcbinset), d - half - pcbfromtop]);
    }   
    
    // SUPPORTS ON TOP
    
    // top pokey dinguses
    translate([thickness + (rounded / 2),h/2,half])
        cylinder(d - half, thickness, thickness);
    translate([thickness + (rounded / 2),thickness + rounded,half])
        cylinder(d - half, thickness, thickness);
    translate([thickness + (rounded / 2),h - thickness - rounded,half])
        cylinder(d - half, thickness, thickness);
    translate([w - wallfromend - wallwidth,thickness + rounded,half])
        cylinder(d - half, thickness, thickness);
    translate([w - wallfromend - wallwidth,h - thickness - rounded,half])
        cylinder(d - half, thickness, thickness);

     // swampy bounders
    translate([bounderfromtop, bounderinset, half])
        cylinder(d - half, bounderradius, bounderradius);
    translate([bounderfromtop, h - bounderinset, half])
        cylinder(d - half, bounderradius, bounderradius);   
    
    // screw hole support
    translate([centerholefromtop, h/2, d - pcbfromtop])
        cylinder(pcbfromtop, bottomcenterholeouterradius, bottomcenterholeouterradius);    
    
    // friendly board support
    translate([friendlyboardsupportfromtop,h/2, d - pcbfromtop])
        cylinder(pcbfromtop, bounderradius, bounderradius); 
    

}


module rounded_cube(size,dia){
    translate([dia/2, dia/2, dia/2])
    hull() {
        w = size[0] - dia;
        h = size[1] - dia;
        d = size [2] - dia;
        sphere(d=dia);
        translate([0,h,d])sphere(d=dia);
        translate([w,0,d])sphere(d=dia);
        translate([w,h,0])sphere(d=dia);
        translate([w,h,d])sphere(d=dia);
        translate([0,0,d])sphere(d=dia);
        translate([w,0,0])sphere(d=dia);
        translate([0,h,0])sphere(d=dia);
    }
}

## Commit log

2016-10-11 case notes
2016-10-11 added back buttons
2016-10-17 added power supply details
2016-10-17 back button
2016-10-22 added keyboard and cartridge stuff
    [synergycart-bottom.stl, synergycart-top.stl, synergycart.scad]
2016-10-30 updates to carts
    [synergycart-bottom.stl, synergycart-top.stl, synergycart.scad]
2016-12-08 keyboard and case updates
    [actuator.scad, actuator.stl]
2016-12-08 case stuff
